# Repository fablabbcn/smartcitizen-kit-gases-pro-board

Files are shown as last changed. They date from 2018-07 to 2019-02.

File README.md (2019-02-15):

# Smart Citizen Kit 2.0 Gases Pro Board 

[]()


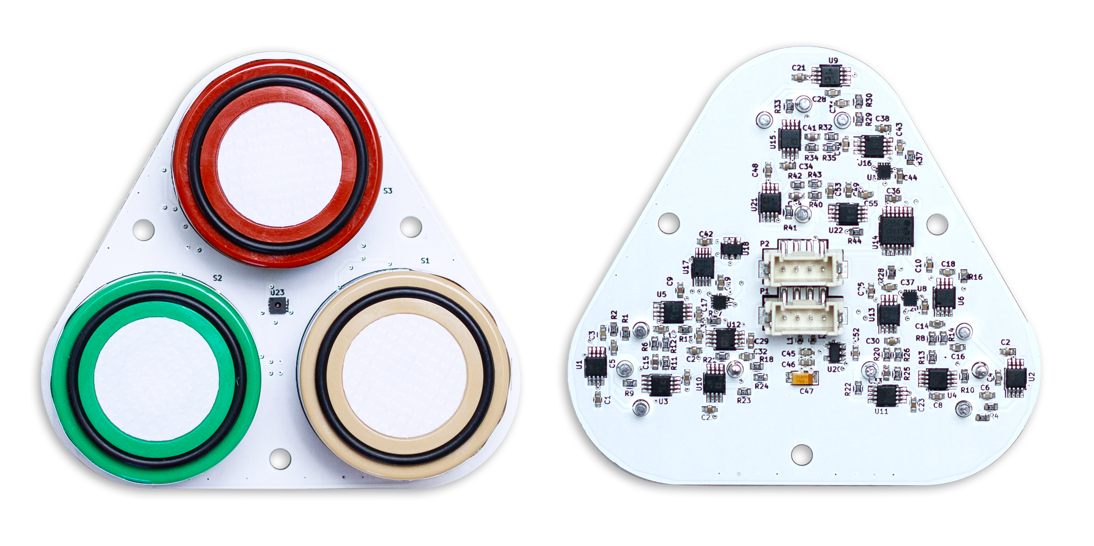
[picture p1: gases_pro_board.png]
Gases Pro Board


### The core firmware (C++)

The technology used:

* Arduino Zero Core
* Platformio

#### Uploading the firmware to the board

After clonning the repository:

1. In folder ./firmware run:

  * `pio run`

2. This step will **take a while**. Once it finished plug the board over USB and run:

  * `pio run -t upload`

## Documentation

Full documentation under development. Follow the [forum](https://forum.smartcitizen.me/) and [twitter](https://twitter.com/SmartCitizenKit) for updates.

## Related Smart Citizen repositories

* Smart Citizen Kit 2.0 [github.com/fablabbcn/smartcitizen-kit-20](https://github.com/fablabbcn/smartcitizen-kit-20)
* Platform Core API [github.com/fablabbcn/smartcitizen-api](https://github.com/fablabbcn/smartcitizen-api)
* Platform Web [github.com/fablabbcn/smartcitizen-web](https://github.com/fablabbcn/smartcitizen-web)
* Platform Onboarding [github.com/fablabbcn/smartcitizen-onboarding-app](https://github.com/fablabbcn/smartcitizen-onboarding-app)
* Kit Enclosures [github.com/fablabbcn/smartcitizen-enclosures](https://github.com/fablabbcn/smartcitizen-enclosures)
* Useful software resources for communities [github.com/fablabbcn/smartcitizen-toolkit](https://github.com/fablabbcn/smartcitizen-toolkit)

## License

All the software unless stated is released under [GNU GPL v3.0](https://github.com/fablabbcn/smartcitizen-kit-20/blob/master/LICENSE) and the hardware design files under [CERN OHL v1.2](https://github.com/fablabbcn/smartcitizen-kit-20/blob/master/hardware/LICENSE)

## Credits

Smart Citizen Team 2012-18

## Funding

This work has received funding from the European Union's Horizon 2020 research and innovation program under the grant agreement [No. 689954](https://cordis.europa.eu/project/rcn/202639_en.html)

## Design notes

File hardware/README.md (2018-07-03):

Smart Citizen Kit 2.0 PM Board Hardware
=======================================

This folder contains the KiCad design files for the Smart Citizen Kit 2.0 PM Board

## Folders

* **SCK_2.0_GASES_PRO_BOARD_rev3** The SCK Gases Pro Alphasense Driver Board
* **SCK_2.0_GASES_PRO_BOARD_TEST_UTIL_rev2** The SCK Gases Pro Calibration and Test Util

## License

All the software is released under [GNU GPL v3.0](https://github.com/fablabbcn/smartcitizen-kit-20/blob/master/LICENSE) and the hardware design files under [CERN OHL v1.2](https://github.com/fablabbcn/smartcitizen-kit-20/blob/master/hardware/LICENSE)

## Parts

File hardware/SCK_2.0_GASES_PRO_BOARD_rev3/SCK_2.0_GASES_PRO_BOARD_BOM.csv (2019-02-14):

Id | Designator | Package | Quantity | Designation | Manufacturer | Manufacturer Part Number | Description | Mouser Part Number | Mouser Alternative Part Number | Mouser Stock | Digikey Part Number | Digikey Stock | Seeedstudio Part Number | Seeedstudio Stock
1 | U7,U8,U19 | QFN14(2X2MM) | 3 | TPL-0102 | Texas Instruments | TPL0102-100RUCR | Digital Potentiometer ICs Digital Potentiometer ICs 256 Taps Dual Ch Digital Pot | 595-TPL0102-100RUCR |  |  | 296-28379-1-ND
4 | U2,U1,U3,U4,U9,U10,U11,U15,U21 | MSOP-8_3x3mm_Pitch0.65mm | 9 | ADA4528-1 | Analog Devices Inc. | ADA4528-1ARMZ | Precision Amplifiers Precision Amplifiers 5V Ultralow Noise Zero-Drift RRIO Dual | 584-ADA4528-1ARMZ |  |  | ADA4528-1ARMZ-R7CT-ND
6 | U6,U5,U12,U13,U16,U22 | MSOP-8_3x3mm_Pitch0.65mm | 6 | ADA4528-2 | Analog Devices Inc. | ADA4528-2ARMZ | Precision Amplifiers Precision Amplifiers 18V LowPower RRIO Untrimmed CmosAmp | 584-ADA4528-2ARMZ |  |  | ADA4528-2ARMZ-R7CT-ND
21 | U14 | TSSOP-14_4.4x5mm_Pitch0.65mm | 1 | MCP3424 | Microchip | MCP3424-E/ST | Analog to Digital Converters - ADC Analog to Digital Converters - ADC 18B delta-sigma ADC dual Ch 4sps | 579-MCP3424-E/ST |  |  | MCP3424-E/ST-ND
22 | U18 | SOT-23-6 | 1 | 24AA025UID | Microchip | 24AA025UIDT-I/OT | EEPROM EEPROM 2K I2C EE Unique ID | 579-24AA025UIDT-I/OT |  |  | 24AA025UIDT-I/OTCT-ND
23 | U20 | SOT-23-5 | 1 | REF-1930 | Texas Instruments | REF1930AIDDCT | Voltage References Voltage References Dual Output Vref & Vref/2 Voltage Ref | 595-REF1930AIDDCT |  |  | 296-38443-1-ND
24 | U23 | DFN-6-1EP_3x3mm_Pitch0.95mm | 1 | SHT31 | Sensirion | SHT31-DIS-B | Board Mount Humidity Sensors Board Mount Humidity Sensors +/- 2%RH 8-PIN DFN pkg | 403-SHT31-DIS-F |  |  | 1649-1066-1-ND
25 | U17 | MSOP-10_3x3mm_Pitch0.5mm | 1 | MCP3423 | Microchip | MCP3423-E/UN | Analog to Digital Converters - ADC 18B delta-sigma ADC dual Ch 4sps | 579-MCP3423-E/UN |  |  | MCP3423-E/UN-ND
3 | S3,S2,S1 | Alphasense_B-4 | 12 | Alphasense_B_Conector | Harwin | H3183-01 | Circuit Board Hardware - PCB Circuit Board Hardware - PCB 1mm PC BOARD SOCKET TIN | 855-H3183-01 |  |  | 952-1468-ND
8 | P2,P1 | HW4-SMD-2.0 | 2 | CONN_01X04 | Seedstudio | CONN_01X04 | 1125S-SMT-4P |  |  |  |  |  | 320110030
15 | L1,L2 | R_0402 | 2 | MPZ1005S121C | TDK | MPZ1005S121C | Ferrite Beads Ferrite Beads 120ohms, 1.2A 0.09ohms | 810-MPZ1005S121C
5 | C20,C1,C2,C7,C8,C9,C10,C19,C21,C22,C23,C24,C25,C34,C36,C38,C42,C44,C46,C48,C49,C52 | C_0603 | 22 | 100n | AVX | 06033C104K4T2A | Multilayer Ceramic Capacitors MLCC - SMD/SMT 25V .1uF X7R 0603 10% Tol | 581-06033C104K4
9 | C3,C4,C5,C6,C28,C31 | C_0603 | 6 | 20n | AVX | 0603ZC223JAT2A | Multilayer Ceramic Capacitors MLCC - SMD/SMT Multilayer Ceramic Capacitors MLCC - SMD/SMT 10V .022uF X7R 0603 5% Tol | 581-0603ZC223JAT2A | 710-885012206042 |  | 0603ZC223JAT2A-ND
10 | C11,C12,C26,C27,C39,C50 | C_0603 | 6 | 220n | AVX | 0603ZC224JAT2A | Multilayer Ceramic Capacitors MLCC - SMD/SMT Multilayer Ceramic Capacitors MLCC - SMD/SMT 10V .22uF X7R 0603 5% Tol | 581-0603ZC224J |  |  | 478-6035-1-ND
11 | C13,C14,C29,C30,C40,C53 | C_0603 | 6 | 2.2µ | AVX | 0603ZC225KAT2A | Multilayer Ceramic Capacitors MLCC - SMD/SMT Multilayer Ceramic Capacitors MLCC - SMD/SMT 10V 2.2uF X7R 0603 10% Tol | 581-0603ZC225KAT2A
12 | C15,C16,C32,C33,C41,C54 | C_0603 | 6 | 6.8µ | TDK | C1608X5R1A685K080AC | Multilayer Ceramic Capacitors MLCC - SMD/SMT Multilayer Ceramic Capacitors MLCC - SMD/SMT 0805 6.8uF 10volts X7R 10% | 810-C2012X7R1A685K1C |  |  | 445-14529-1-ND
13 | C17,C18,C35,C37,C43,C45,C55 | C_0603 | 7 | 10n | AVX | 0603ZC103JAT2A | Multilayer Ceramic Capacitors MLCC - SMD/SMT Multilayer Ceramic Capacitors MLCC - SMD/SMT 10V .01uF X7R 0603 5% Tol | 581-0603ZC103J |  |  | 0603ZC103JAT2A-ND
14 | C47 | CP_Tantalum_Case-A_EIA-3216-18_Reflow | 1 | 10µ Tan. | AVX | TRJA106K010R1800 | Tantalum Capacitors - Solid SMD Tantalum Capacitors - Solid SMD 10uF +/-10% 10V ESR=1800 | 581-TRJA106K010R1800
16 | R1,R2,R3,R4,R15,R16,R27,R28,R29,R30,R37,R44 | R_0603 | 12 | 10kΩ | Vishay | MCT06030C1002FP500 | Thin Film Resistors - SMD Thin Film Resistors - SMD .1W 10Kohms 1% 0603 50ppm Auto | 594-MCT06030C1002FP5 |  |  | MCT0603-10.0K-CFCT-ND
17 | R5,R7,R17,R19,R31,R39 | R_0603 | 6 | 150kΩ | Vishay | MCT06030C1503FP500 | Thin Film Resistors - SMD Thin Film Resistors - SMD .1W 150Kohm 1% 0603 50ppm Auto | 594-MCT06030C1503FP5 |  |  | MCT0603-150K-CFCT-ND
18 | R6,R8,R11,R13,R18,R20,R23,R25,R32,R34,R40,R42 | R_0603 | 12 | 5.6kΩ | Vishay | MCT06030C5601FP500 | Thin Film Resistors - SMD Thin Film Resistors - SMD .1W 5.6Kohm 1% 0603 50ppm Auto | 594-MCT06030C5601FP5 |  |  | MCT0603-5.60K-CFCT-ND
19 | R9,R10,R21,R22,R33,R41 | R_0603 | 6 | 100Ω | Vishay | MCT06030C1000FP500 | Thin Film Resistors - SMD Thin Film Resistors - SMD .1W 100ohm 1% 0603 50ppm Auto | 594-MCT06030C1000FP5 |  |  | MCT0603-100-CFCT-ND
20 | R12,R14,R24,R26,R35,R43 | R_0603 | 6 | 12kΩ | Vishay | MCT06030C1202FP500 | Thin Film Resistors - SMD Thin Film Resistors - SMD .1W 12Kohm 1% 0603 50ppm Auto | 594-MCT06030C1202FP5 |  |  | MCT0603-12.0K-CFCT-ND
 | *All resistor Thin metal film
 | All capacitor MMLC X7R (except tantalum)

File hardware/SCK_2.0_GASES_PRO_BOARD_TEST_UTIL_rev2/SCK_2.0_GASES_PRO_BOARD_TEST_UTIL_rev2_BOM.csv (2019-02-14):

Id | Designator | Package | Quantity | Designation | Manufacturer Part Number | Description | Mouser Part Number | Mouser Alternative Part Number | Mouser Stock | Digikey Part Number | Digikey Stock | Seeedstudio Part Number | Seeedstudio Stock
2 | U3,U1 | TSSOP-14_4.4x5mm_Pitch0.65mm | 2 | MCP6V34-E/ST
3 | U4,U2 | TSSOP-14_4.4x5mm_Pitch0.65mm | 2 | MCP4651-103/ST |  | Digital pot. 10K | 579-MCP4651-103/ST
4 | A | 1pin | 1 | curr_out_2 | Keystone |  | 534-1402-3
5 | W | 1pin | 1 | curr_out_1 | Keystone |  | 534-1402-3
6 | Power/Comm | HW4-SMD-2.0 | 1 | CONN_01X04 |  | 1125S-SMT-4P |  |  |  |  |  | 320110030
7 | U5 | SOT-23-5 | 1 | REF-1930 | Texas Instruments | REF1930AIDDCT | Voltage References Voltage References Dual Output Vref & Vref/2 Voltage Ref | 595-REF1930AIDDCT |  | Yes | 296-38443-1-ND | Yes
8 | C1,C3,C6,C7,C10,C11,C12,C13 | C_0603_HandSoldering | 8 | 100n
9 | C2,C8 | C_0603_HandSoldering | 2 | 10n
10 | C4 | C_0603_HandSoldering | 1 | 1u
11 | C5,C9 | C_0603_HandSoldering | 2 | 22p
12 | R2,R12 | R_0805_HandSoldering | 2 | 1M 0.5%
13 | R4,R6,R8,R9,R10,R14,R16,R18,R19,R20,R21,R25 | R_0603_HandSoldering | 12 | 100k 0.5% o 0.1%
14 | R5,R15 | R_0603_HandSoldering | 2 | 100
15 | R7,R17 | R_0603_HandSoldering | 2 | 1k
16 | R22,R26 | R_0603_HandSoldering | 2 | 4.3M
 | All resistors metal film
 | All capacitors X7R or C0G

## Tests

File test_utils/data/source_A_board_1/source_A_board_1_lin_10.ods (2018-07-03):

Corriente pedida |  | corriente leida_A | diff
-1400 | - | -1400.23 | 0.23 | pot0A_g | 3 | - | pot1A_f | 196
-1399 | - | -1399.19 | 0.19 | pot0A_g | 3 | - | pot1A_f | 207
-1398 | - | -1398.25 | 0.25 | pot0A_g | 3 | - | pot1A_f | 217
-1397 | - | -1397.17 | 0.17 | pot0A_g | 3 | - | pot1A_f | 228
-1396 | - | -1396.23 | 0.23 | pot0A_g | 3 | - | pot1A_f | 238
-1395 | - | -1395.19 | 0.19 | pot0A_g | 3 | - | pot1A_f | 249
-1394 | - | -1394.14 | 0.14 | pot0A_g | 4 | - | pot1A_f | 90
-1393 | - | -1393.2 | 0.2 | pot0A_g | 4 | - | pot1A_f | 100
-1392 | - | -1392.17 | 0.17 | pot0A_g | 4 | - | pot1A_f | 111
-1391 | - | -1391.2 | 0.2 | pot0A_g | 4 | - | pot1A_f | 121
-1390 | - | -1390.13 | 0.13 | pot0A_g | 4 | - | pot1A_f | 132
-1389 | - | -1389.17 | 0.17 | pot0A_g | 4 | - | pot1A_f | 142
-1388 | - | -1388.13 | 0.13 | pot0A_g | 4 | - | pot1A_f | 153
-1387 | - | -1387.14 | 0.14 | pot0A_g | 4 | - | pot1A_f | 163
-1386 | - | -1386.11 | 0.11 | pot0A_g | 4 | - | pot1A_f | 174
-1385 | - | -1385.17 | 0.17 | pot0A_g | 4 | - | pot1A_f | 184
-1384 | - | -1384.09 | 0.09 | pot0A_g | 4 | - | pot1A_f | 195
-1383 | - | -1383.16 | 0.16 | pot0A_g | 4 | - | pot1A_f | 205
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

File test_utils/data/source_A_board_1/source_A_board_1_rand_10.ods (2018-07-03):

item | Corriente pedida |  | delay |  | corriente leida_A | diff
0 | -1102 | -> | 2000 | - | -1101.45 | -0.55
1 | 668 | -> | 2270 | - | 667.7 | 0.3
2 | -341 | -> | 1509 | - | -340.67 | -0.33
3 | 467 | -> | 1308 | - | 466.73 | 0.27
4 | 395 | -> | 572 | - | 394.97 | 0.03
5 | -492 | -> | 1387 | - | -491.64 | -0.36
6 | 813 | -> | 1805 | - | 812.59 | 0.41
7 | -893 | -> | 2206 | - | -892.69 | -0.31
8 | -374 | -> | 1019 | - | -374.25 | 0.25
9 | -48 | -> | 826 | - | -48.45 | 0.45
10 | 37 | -> | 585 | - | 36.64 | 0.36
11 | 556 | -> | 1019 | - | 555.48 | 0.52
12 | -1053 | -> | 2109 | - | -1052.72 | -0.28
13 | -1146 | -> | 593 | - | -1145.55 | -0.45
14 | 837 | -> | 2483 | - | 836.59 | 0.41
15 | 1191 | -> | 854 | - | 1190.25 | 0.75
16 | 30 | -> | 1661 | - | 30.16 | -0.16
17 | 1084 | -> | 1554 | - | 1083.53 | 0.47
18 | -1126 | -> | 2710 | - | -1125.69 | -0.31
19 | 122 | -> | 1748 | - | 121.67 | 0.33
20 | -1271 | -> | 1893 | - | -1270.7 | -0.3
21 | 310 | -> | 2081 | - | 309.61 | 0.39
22 | -953 | -> | 1763 | - | -952.81 | -0.19
23 | 1194 | -> | 2647 | - | 1193.56 | 0.44
24 | -912 | -> | 2606 | - | -911.87 | -0.13
25 | -1353 | -> | 941 | - | -1352.44 | -0.56
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

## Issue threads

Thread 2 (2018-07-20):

No need to wait after Wire.requestFrom().

Koepel, 2018-07-20:
The timeout after Wire.requestFrom() with millis() in the file "GasesBoardTester.cpp" is not needed.
Explanation: [Common-mistakes#1](https://github.com/Koepel/How-to-use-the-Arduino-Wire-library/wiki/Common-mistakes#1)

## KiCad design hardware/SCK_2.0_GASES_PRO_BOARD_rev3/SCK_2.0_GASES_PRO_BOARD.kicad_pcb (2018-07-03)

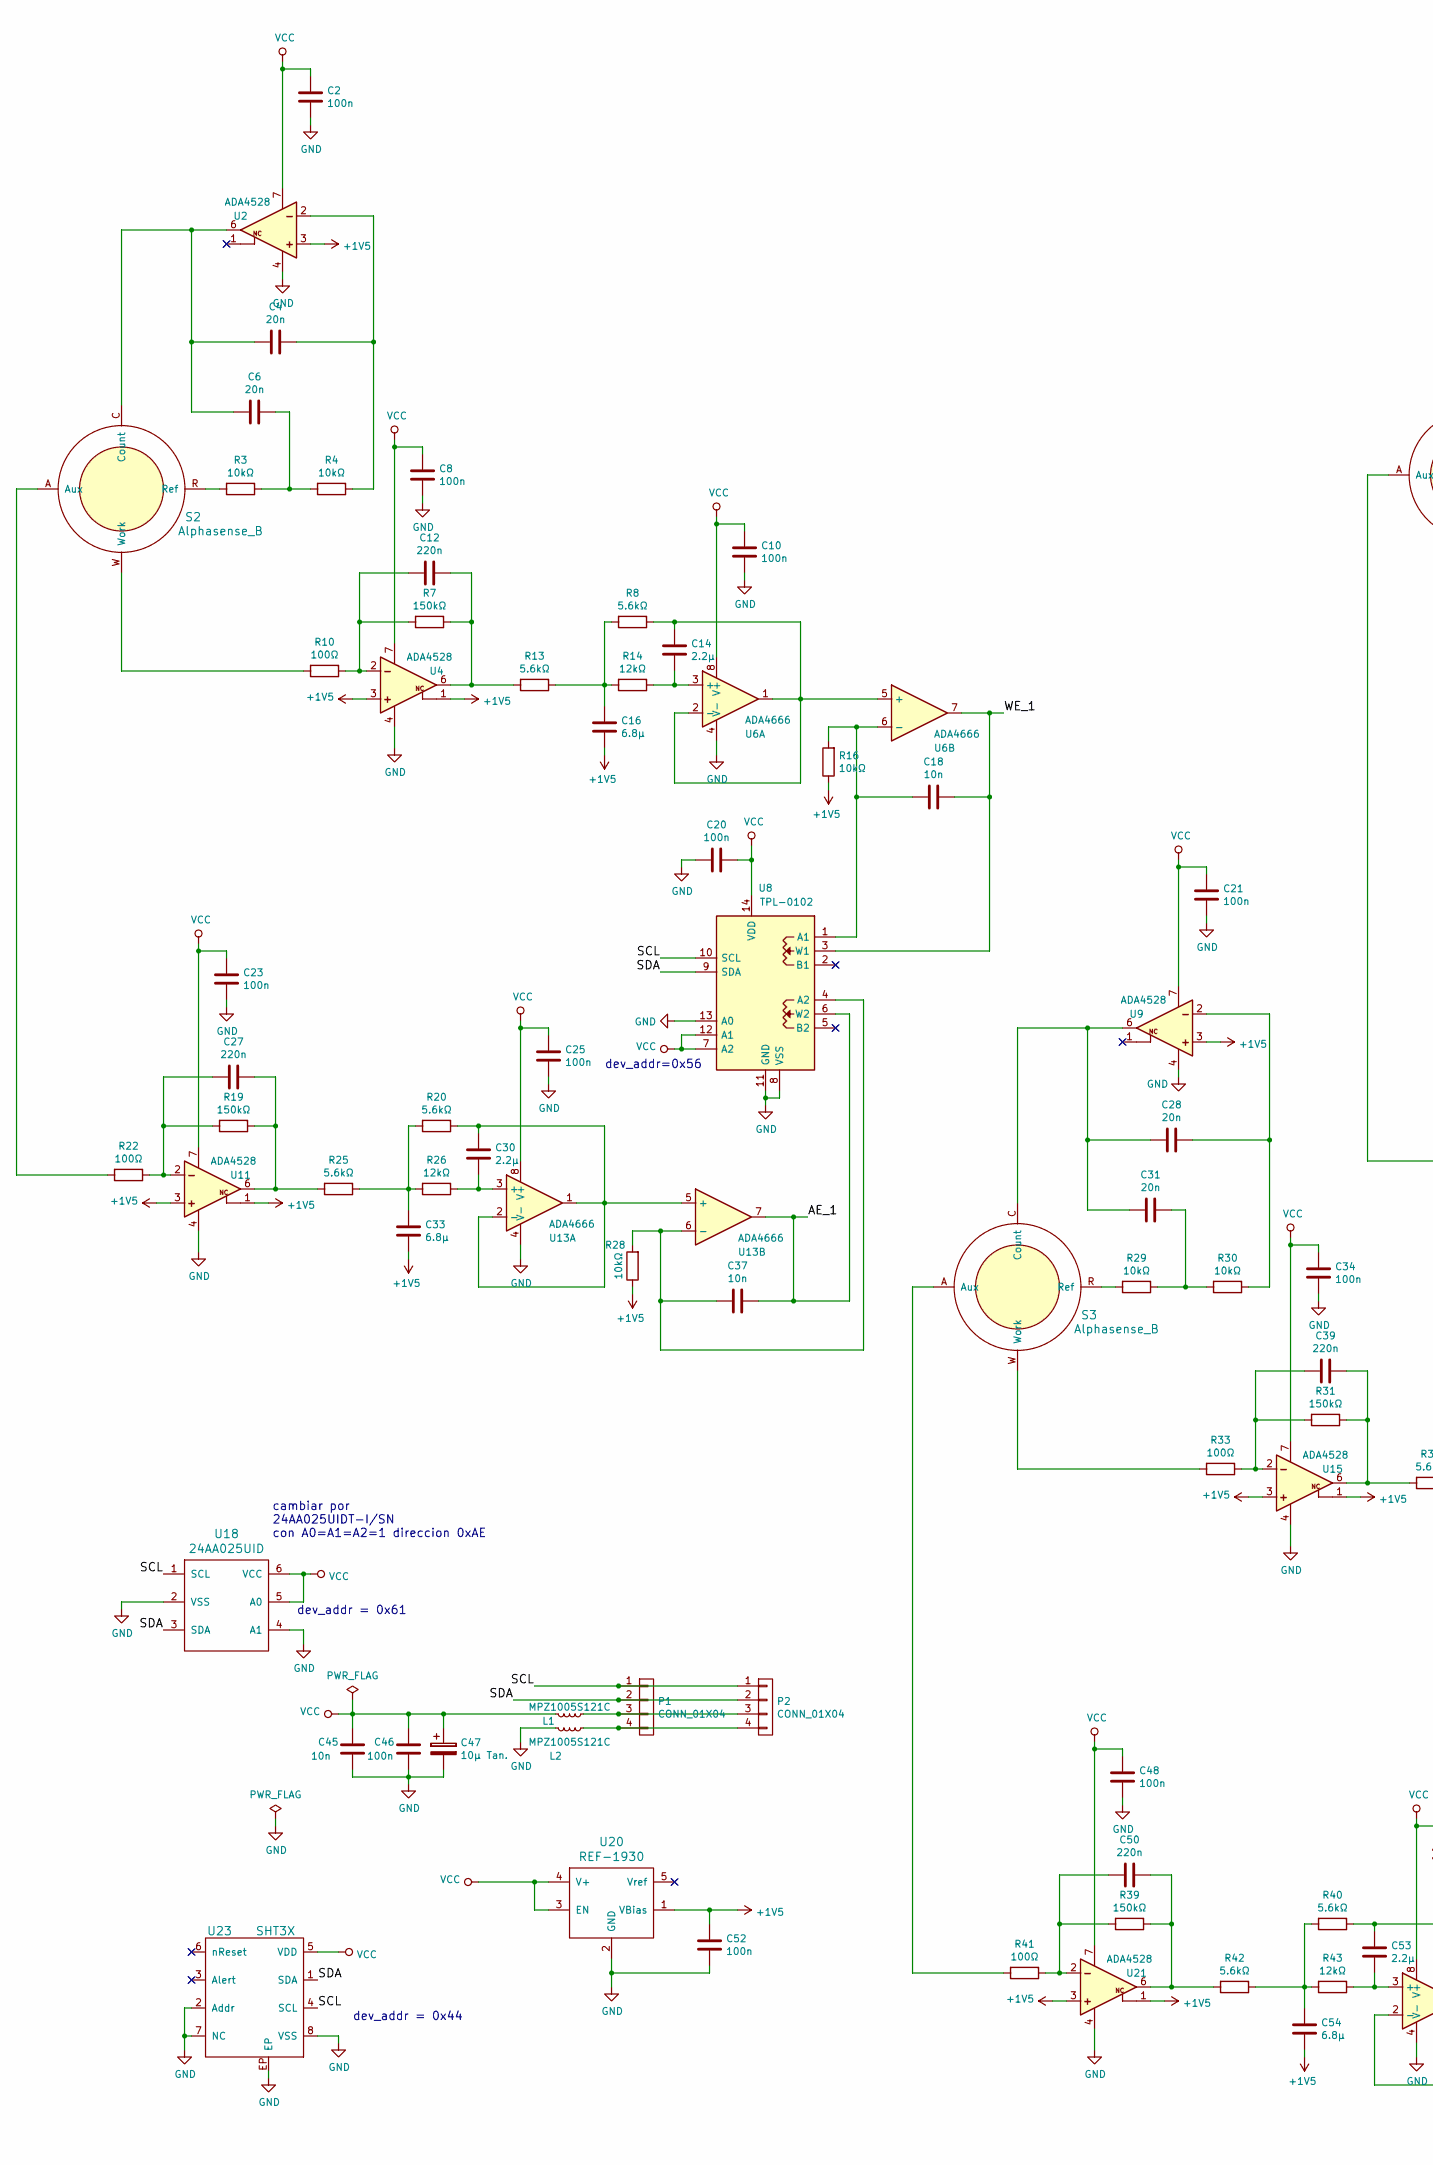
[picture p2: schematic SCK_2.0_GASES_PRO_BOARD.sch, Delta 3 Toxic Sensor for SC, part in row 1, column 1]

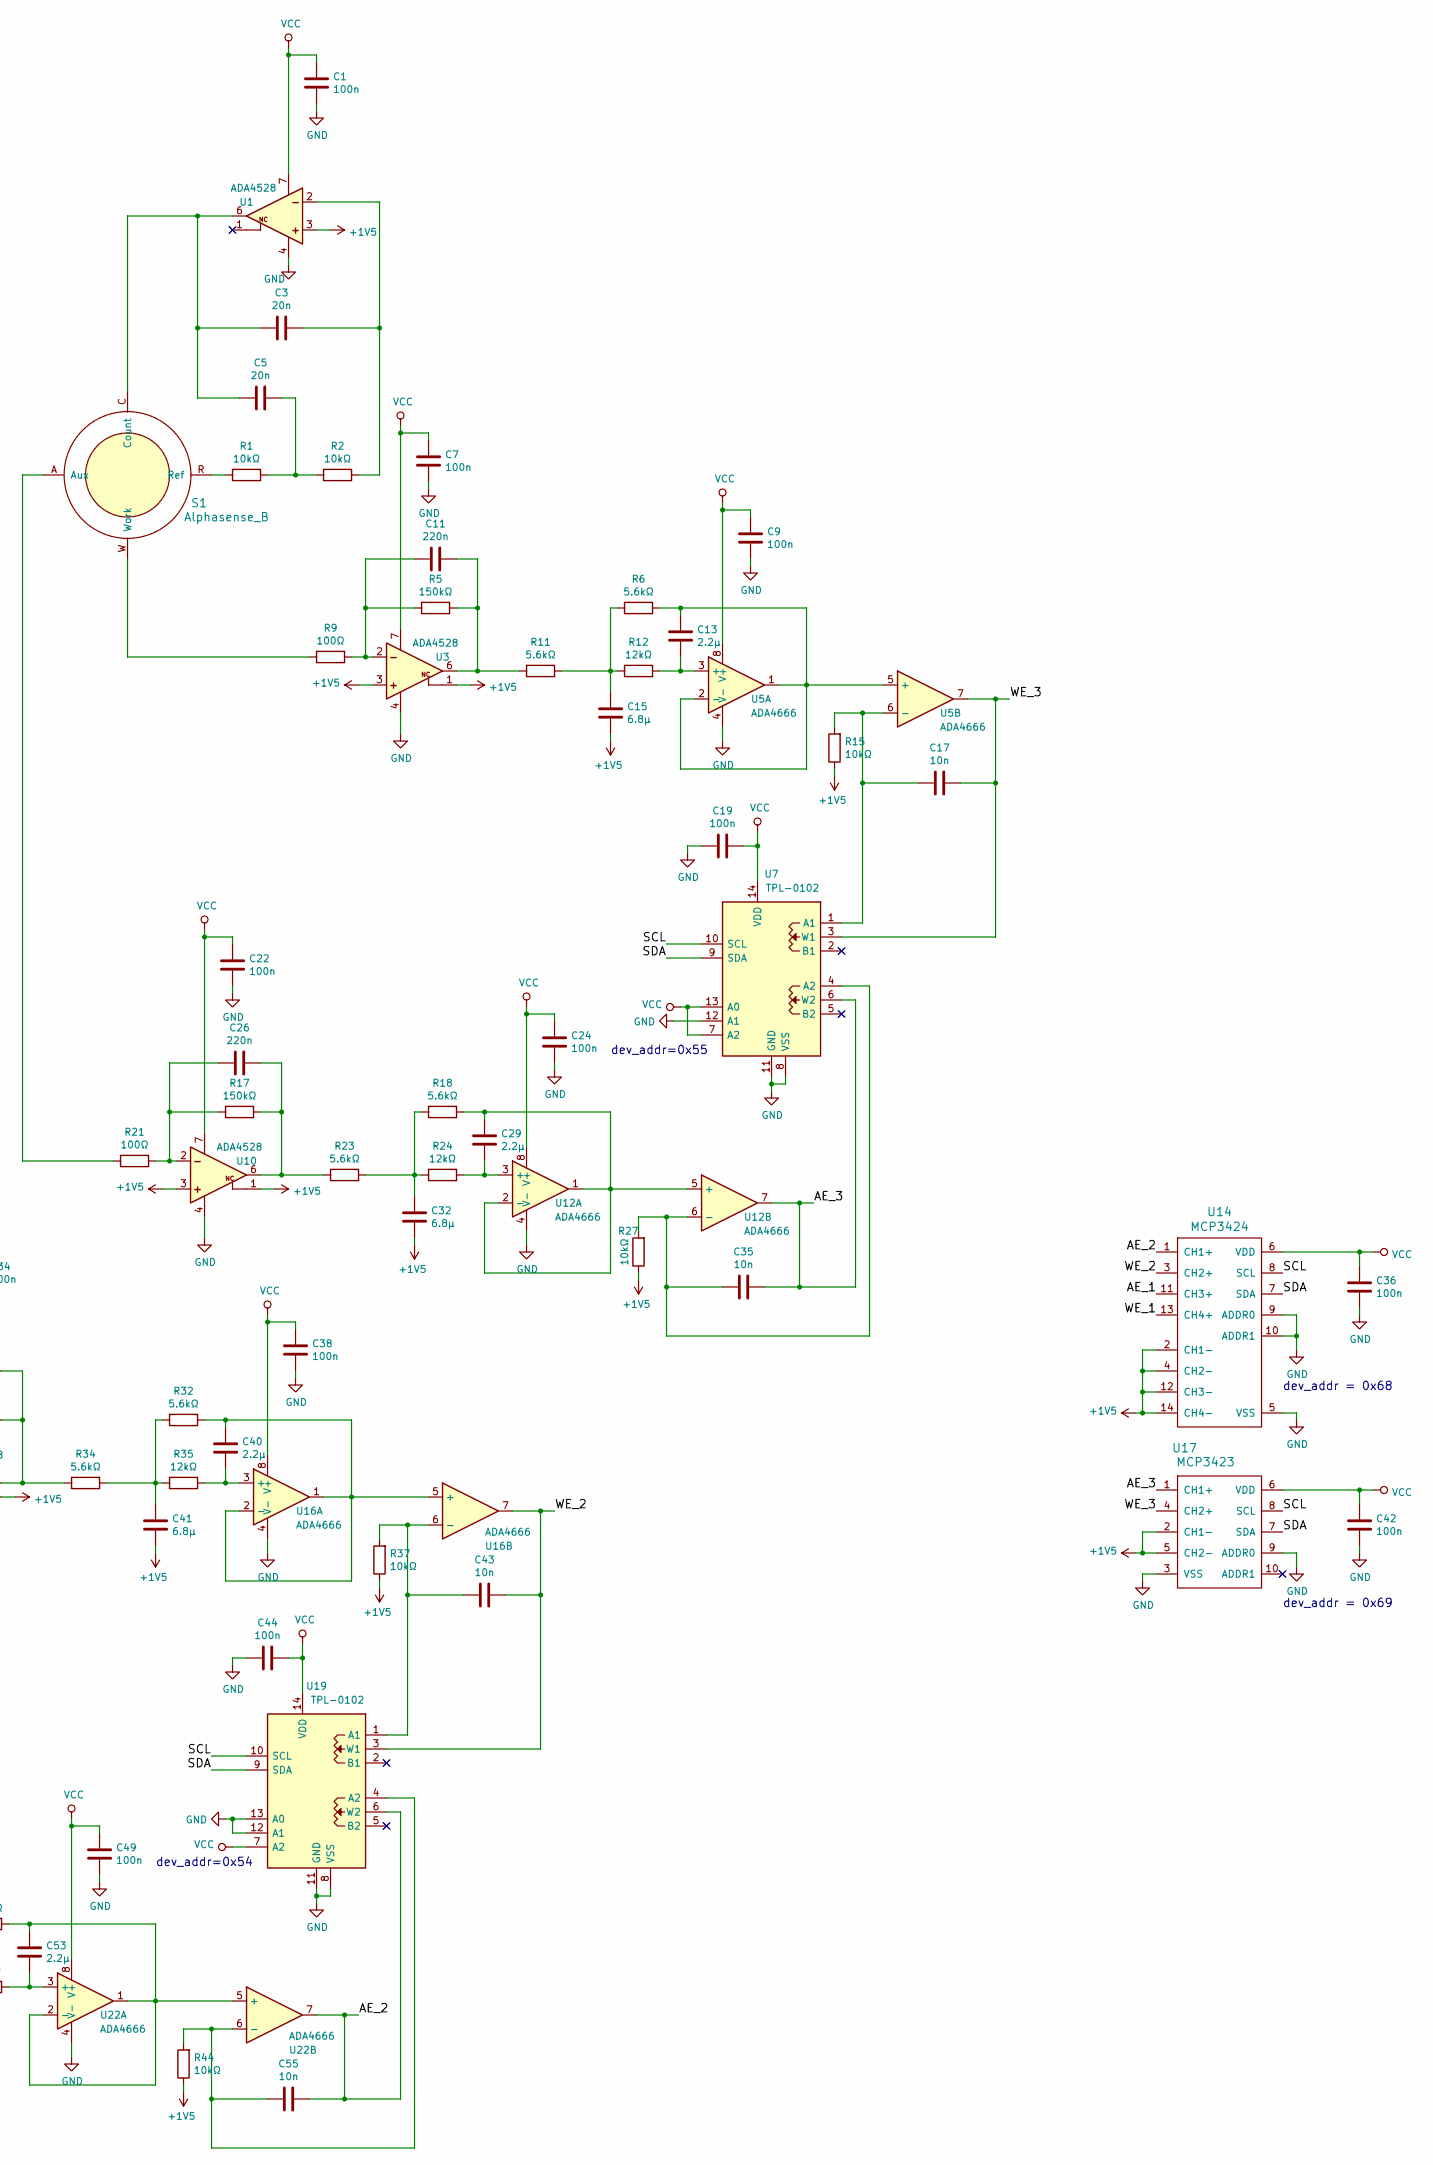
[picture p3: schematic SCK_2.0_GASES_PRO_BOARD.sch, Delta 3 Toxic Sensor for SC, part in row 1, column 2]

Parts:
C1, C2, C7, C8, C9, C10, C19, C20, C21, C22, C23, C24, C25, C34, C36, C38, C42, C44, C46, C48, C49, C52: 100n; C_0603
C3, C4, C5, C6, C28, C31: 20n; C_0603
C11, C12, C26, C27, C39, C50: 220n; C_0603
C13, C14, C29, C30, C40, C53: 2.2µ; C_0603
C15, C16, C32, C33, C41, C54: 6.8µ; C_0603
C17, C18, C35, C37, C43, C45, C55: 10n; C_0603
C47: 10µ Tan.; CP_Tantalum_Case-A_EIA-3216-18_Reflow
L1, L2: MPZ1005S121C; R_0402
P1, P2: CONN_01X04; HW4-SMD-2.0
R1, R2, R3, R4, R15, R16, R27, R28, R29, R30, R37, R44: 10kΩ; R_0603
R5, R7, R17, R19, R31, R39: 150kΩ; R_0603
R6, R8, R11, R13, R18, R20, R23, R25, R32, R34, R40, R42: 5.6kΩ; R_0603
R9, R10, R21, R22, R33, R41: 100Ω; R_0603
R12, R14, R24, R26, R35, R43: 12kΩ; R_0603
S1, S2, S3: Alphasense_B; Alphasense_B-4
U1, U2, U3, U4, U9, U10, U11, U15, U21: ADA4528; MSOP-8_3x3mm_Pitch0.65mm
U5, U6, U12, U13, U16, U22: ADA4666; MSOP-8_3x3mm_Pitch0.65mm
U7, U8, U19: TPL-0102; QFN14(2X2MM)
U14: MCP3424; TSSOP-14_4.4x5mm_Pitch0.65mm
U17: MCP3423; MSOP-10_3x3mm_Pitch0.5mm
U18: 24AA025UID; SOT-23-6
U20: REF-1930; SOT-23-5
U23: SHT3X; DFN-8-1EP_2x2mm_Pitch0.5mm

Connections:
+1V5: C15.1, C16.1, C32.1, C33.1, C41.1, C52.1, C54.1, R15.1, R16.1, R27.1, R28.1, R37.1, R44.1, U1.3 (NOT-INV.INPUT), U2.3 (NOT-INV.INPUT), U3.1 (NC), U3.3 (NOT-INV.INPUT), U4.1 (NC), U4.3 (NOT-INV.INPUT), U9.3 (NOT-INV.INPUT), U10.1 (NC), U10.3 (NOT-INV.INPUT), U11.1 (NC), U11.3 (NOT-INV.INPUT), U14.2 (CH1-), U14.4 (CH2-), U14.12 (CH3-), U14.14 (CH4-), U15.1 (NC), U15.3 (NOT-INV.INPUT), U17.2 (CH1-), U17.5 (CH2-), U20.1 (VBias), U21.1 (NC), U21.3 (NOT-INV.INPUT)
/AE_1: C37.2, U8.6 (W2), U13.7, U14.11 (CH3+)
/AE_2: C55.2, U14.1 (CH1+), U19.6 (W2), U22.7
/AE_3: C35.2, U7.6 (W2), U12.7, U17.1 (CH1+)
/SCL: P1.1, P2.1, U7.10 (SCL), U8.10 (SCL), U14.8 (SCL), U17.8 (SCL), U18.1 (SCL), U19.10 (SCL), U23.4 (SCL)
/SDA: P1.2, P2.2, U7.9 (SDA), U8.9 (SDA), U14.7 (SDA), U17.7 (SDA), U18.3 (SDA), U19.9 (SDA), U23.1 (SDA)
/WE_1: C18.2, U6.7, U8.3 (W1), U14.13 (CH4+)
/WE_2: C43.2, U14.3 (CH2+), U16.7, U19.3 (W1)
/WE_3: C17.2, U5.7, U7.3 (W1), U17.4 (CH2+)
GND: C1.2, C2.2, C7.2, C8.2, C9.2, C10.2, C19.1, C20.1, C21.2, C22.2, C23.2, C24.2, C25.2, C34.2, C36.2, C38.2, C42.2, C44.1, C45.2, C46.2, C47.2, C48.2, C49.2, C52.2, L2.2, U1.4 (V-), U2.4 (V-), U3.4 (V-), U4.4 (V-), U5.4 (V-), U6.4 (V-), U7.8 (VSS), U7.11 (GND), U7.12 (A1), U8.8 (VSS), U8.11 (GND), U8.13 (A0), U9.4 (V-), U10.4 (V-), U11.4 (V-), U12.4 (V-), U13.4 (V-), U14.5 (VSS), U14.9 (ADDR0), U14.10 (ADDR1), U15.4 (V-), U16.4 (V-), U17.3 (VSS), U17.9 (ADDR0), U18.2 (VSS), U18.4 (A1), U19.8 (VSS), U19.11 (GND), U19.12 (A1), U19.13 (A0), U20.2 (GND), U21.4 (V-), U22.4 (V-), U23.2 (Addr), U23.7 (NC), U23.8 (VSS), U23.9, U23.EP
unnamed: C3.1, R2.1, U1.2 (INV.INPUT)
unnamed: C3.2, C5.2, S1.C (Count), U1.6 (OUTPUT)
unnamed: C4.1, R4.1, U2.2 (INV.INPUT)
unnamed: C4.2, C6.2, S2.C (Count), U2.6 (OUTPUT)
unnamed: C5.1, R1.1, R2.2
unnamed: C6.1, R3.1, R4.2
unnamed: C11.1, R5.1, R11.2, U3.6 (OUTPUT)
unnamed: C11.2, R5.2, R9.1, U3.2 (INV.INPUT)
unnamed: C12.1, R7.1, R13.2, U4.6 (OUTPUT)
unnamed: C12.2, R7.2, R10.1, U4.2 (INV.INPUT)
unnamed: C13.1, R12.1, U5.3 (+)
unnamed: C13.2, R6.1, U5.1, U5.2 (-), U5.5 (+)
unnamed: C14.1, R14.1, U6.3 (+)
unnamed: C14.2, R8.1, U6.1, U6.2 (-), U6.5 (+)
unnamed: C15.2, R6.2, R11.1, R12.2
unnamed: C16.2, R8.2, R13.1, R14.2
unnamed: C17.1, R15.2, U5.6 (-), U7.1 (A1)
unnamed: C18.1, R16.2, U6.6 (-), U8.1 (A1)
unnamed: C26.1, R17.1, R23.2, U10.6 (OUTPUT)
unnamed: C26.2, R17.2, R21.1, U10.2 (INV.INPUT)
unnamed: C27.1, R19.1, R25.2, U11.6 (OUTPUT)
unnamed: C27.2, R19.2, R22.1, U11.2 (INV.INPUT)
unnamed: C28.1, R30.1, U9.2 (INV.INPUT)
unnamed: C28.2, C31.2, S3.C (Count), U9.6 (OUTPUT)
unnamed: C29.1, R24.1, U12.3 (+)
unnamed: C29.2, R18.1, U12.1, U12.2 (-), U12.5 (+)
unnamed: C30.1, R26.1, U13.3 (+)
unnamed: C30.2, R20.1, U13.1, U13.2 (-), U13.5 (+)
unnamed: C31.1, R29.1, R30.2
unnamed: C32.2, R18.2, R23.1, R24.2
unnamed: C33.2, R20.2, R25.1, R26.2
unnamed: C35.1, R27.2, U7.4 (A2), U12.6 (-)
unnamed: C37.1, R28.2, U8.4 (A2), U13.6 (-)
unnamed: C39.1, R31.1, R34.2, U15.6 (OUTPUT)
unnamed: C39.2, R31.2, R33.1, U15.2 (INV.INPUT)
unnamed: C40.1, R35.1, U16.3 (+)
unnamed: C40.2, R32.1, U16.1, U16.2 (-), U16.5 (+)
unnamed: C41.2, R32.2, R34.1, R35.2
unnamed: C43.1, R37.2, U16.6 (-), U19.1 (A1)
unnamed: C50.1, R39.1, R42.2, U21.6 (OUTPUT)
unnamed: C50.2, R39.2, R41.1, U21.2 (INV.INPUT)
unnamed: C53.1, R43.1, U22.3 (+)
unnamed: C53.2, R40.1, U22.1, U22.2 (-), U22.5 (+)
unnamed: C54.2, R40.2, R42.1, R43.2
unnamed: C55.1, R44.2, U19.4 (A2), U22.6 (-)
unnamed: L1.1, P1.3, P2.3
unnamed: L2.1, P1.4, P2.4
unnamed: R1.2, S1.R (Ref)
unnamed: R3.2, S2.R (Ref)
unnamed: R9.2, S1.W (Work)
unnamed: R10.2, S2.W (Work)
unnamed: R21.2, S1.A (Aux)
unnamed: R22.2, S2.A (Aux)
unnamed: R29.2, S3.R (Ref)
unnamed: R33.2, S3.W (Work)
unnamed: R41.2, S3.A (Aux)
VCC: C1.1, C2.1, C7.1, C8.1, C9.1, C10.1, C19.2, C20.2, C21.1, C22.1, C23.1, C24.1, C25.1, C34.1, C36.1, C38.1, C42.1, C44.2, C45.1, C46.1, C47.1, C48.1, C49.1, L1.2, U1.7 (V+), U2.7 (V+), U3.7 (V+), U4.7 (V+), U5.8 (V+), U6.8 (V+), U7.7 (A2), U7.13 (A0), U7.14 (VDD), U8.7 (A2), U8.12 (A1), U8.14 (VDD), U9.7 (V+), U10.7 (V+), U11.7 (V+), U12.8 (V+), U13.8 (V+), U14.6 (VDD), U15.7 (V+), U16.8 (V+), U17.6 (VDD), U18.5 (A0), U18.6 (VCC), U19.7 (A2), U19.14 (VDD), U20.3 (EN), U20.4 (V+), U21.7 (V+), U22.8 (V+), U23.5 (VDD)

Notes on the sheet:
dev_addr=0x56
dev_addr=0x54
dev_addr=0x55
dev_addr = 0x61
dev_addr = 0x69
dev_addr = 0x68
dev_addr = 0x44
cambiar por 24AA025UIDT-I/SN con A0=A1=A2=1 direccion 0xAE

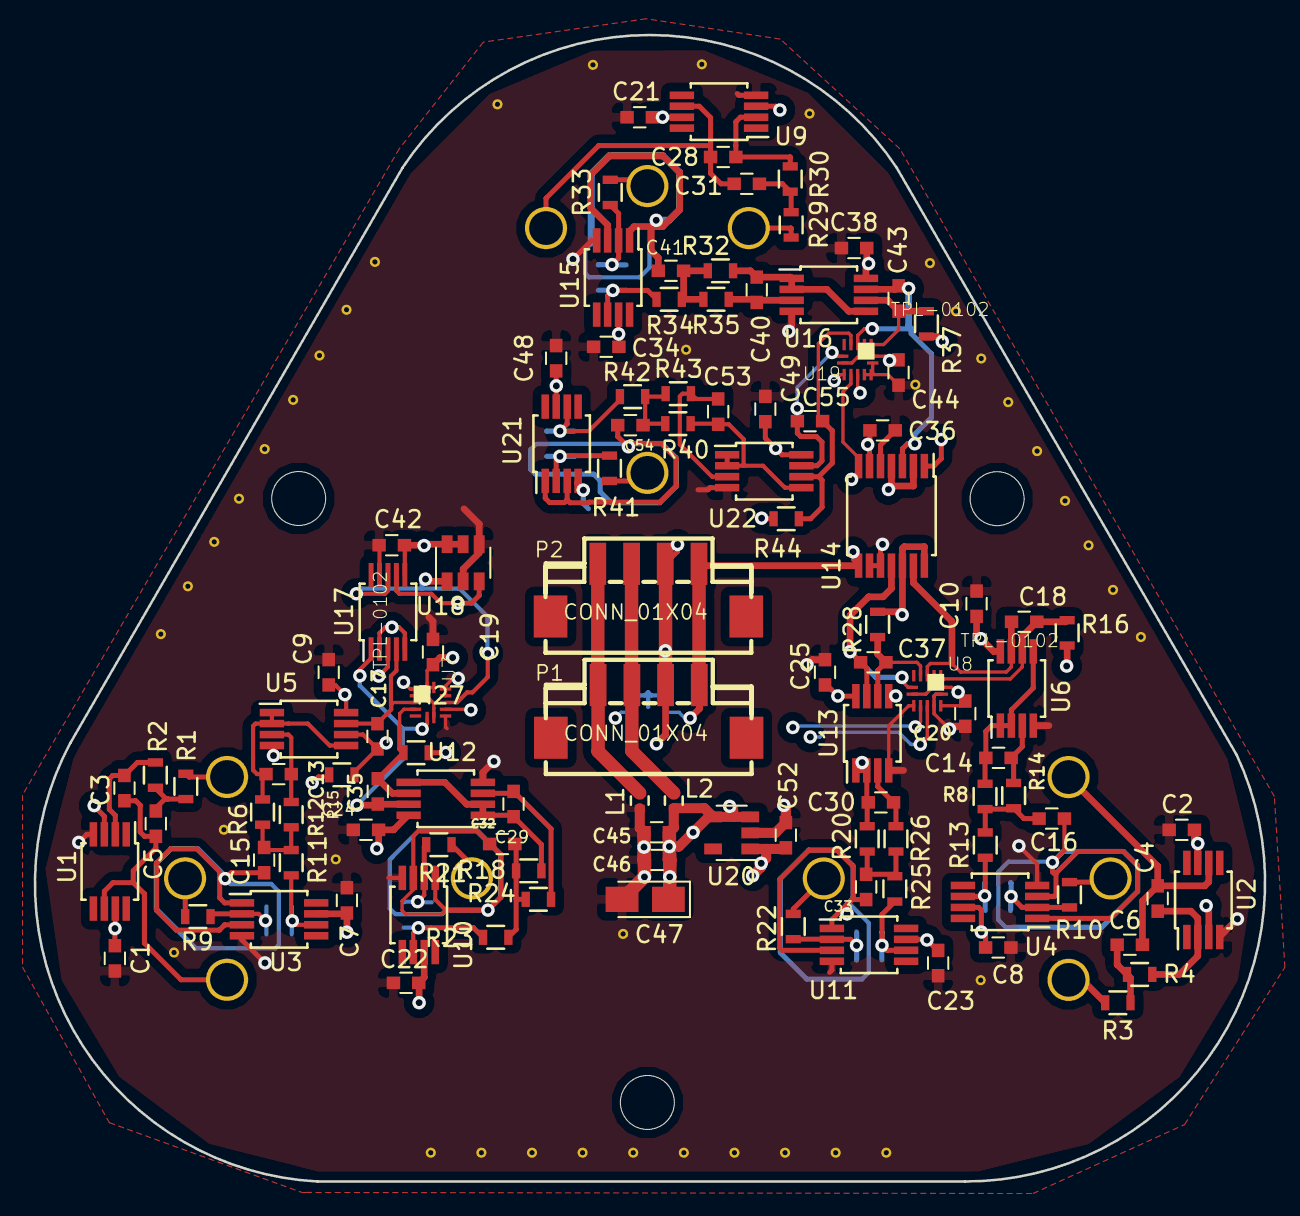
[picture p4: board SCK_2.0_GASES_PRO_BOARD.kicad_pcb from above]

Board: 4 copper layers, 72.9 x 68.0 mm, 126 parts (0 on the bottom side), 67 nets.

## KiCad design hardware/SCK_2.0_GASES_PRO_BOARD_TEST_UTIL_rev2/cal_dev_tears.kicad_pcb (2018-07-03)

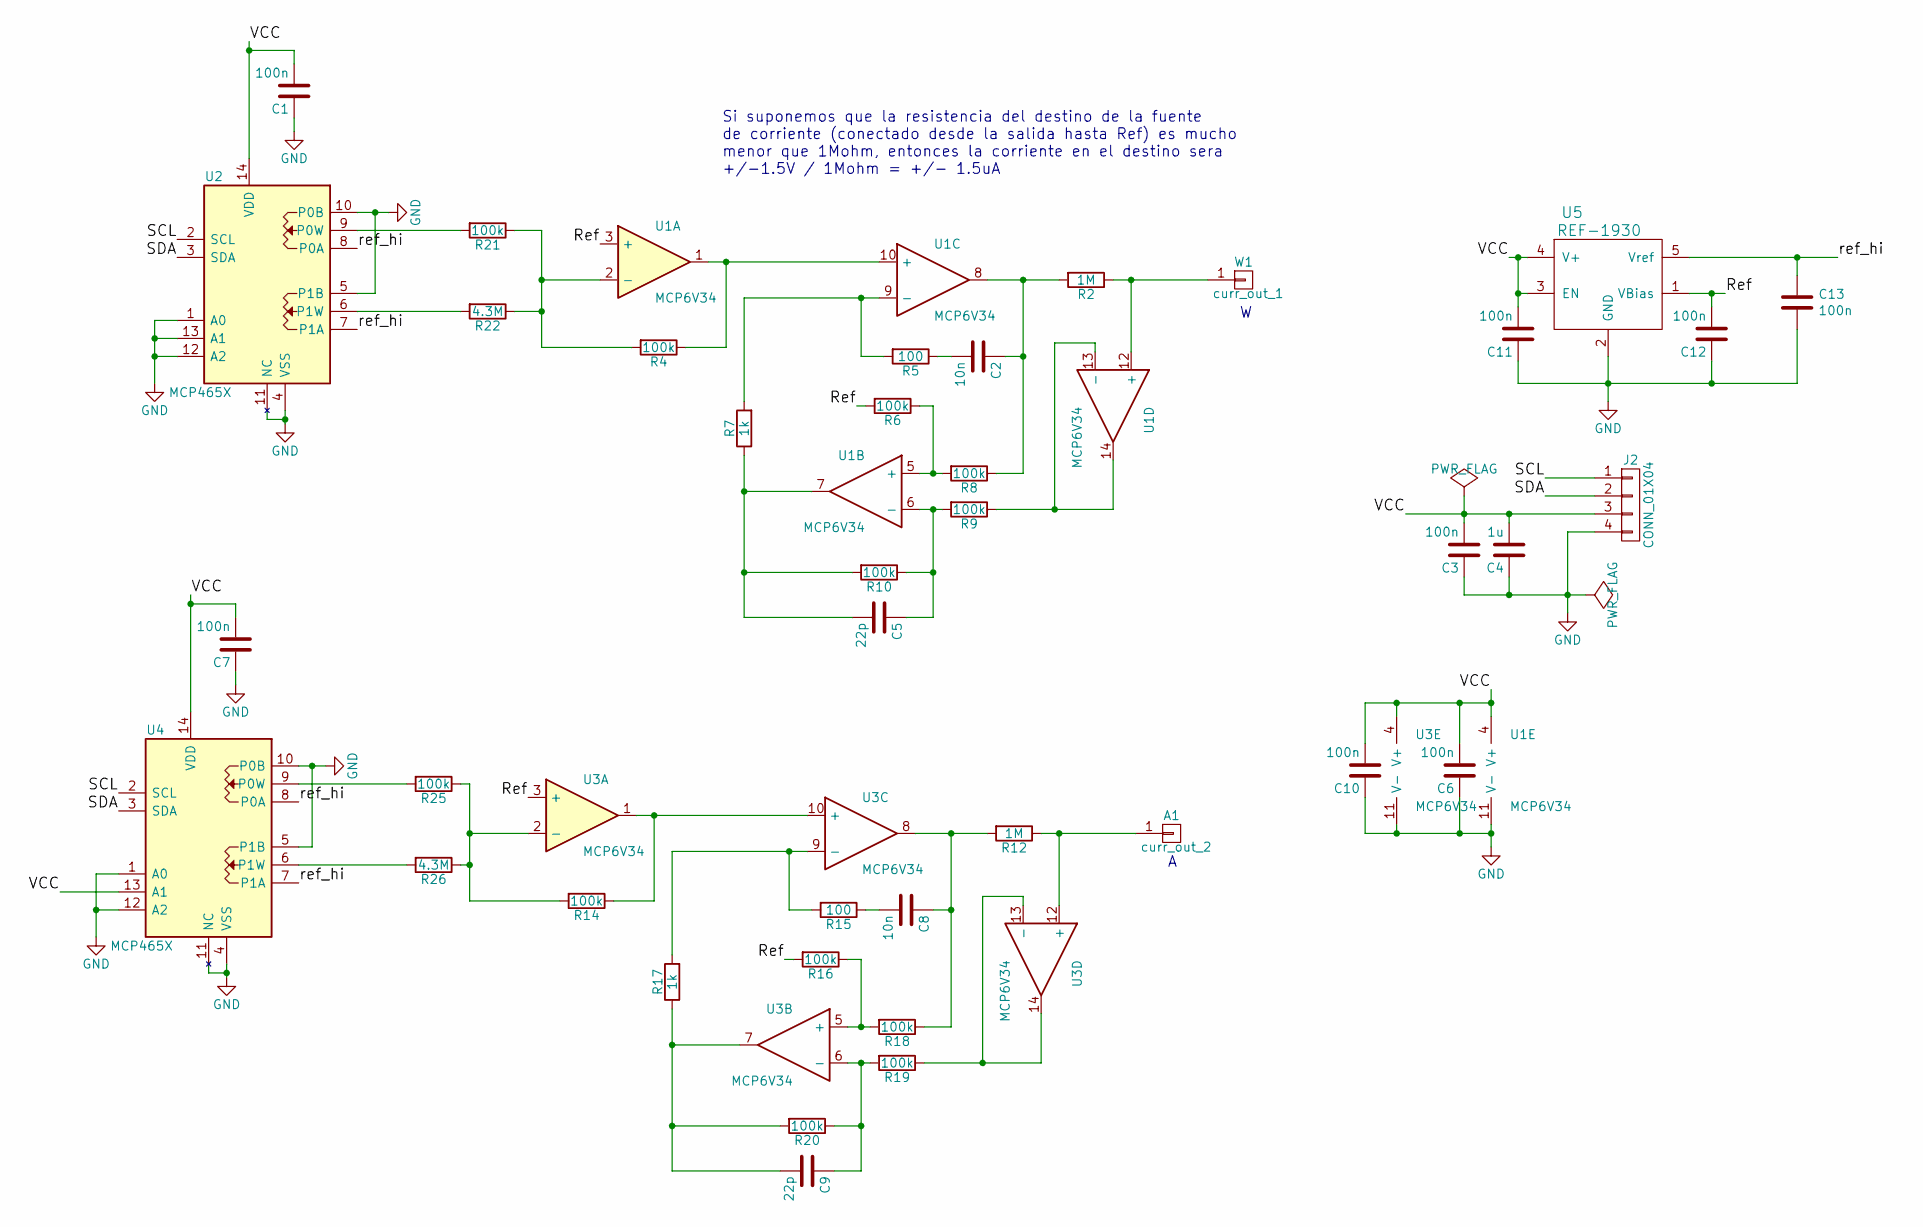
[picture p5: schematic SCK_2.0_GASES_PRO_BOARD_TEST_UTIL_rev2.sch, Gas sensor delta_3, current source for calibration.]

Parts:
A1: curr_out_2; 1pin
C1, C3, C6, C7, C10, C11, C12, C13: 100n; C_0603_HandSoldering
C2, C8: 10n; C_0603_HandSoldering
C4: 1u; C_0603_HandSoldering
C5, C9: 22p; C_0603_HandSoldering
J2: CONN_01X04; HW4-SMD-2.0
R2, R12: 1M; R_0805_HandSoldering
R4, R6, R8, R9, R10, R14, R16, R18, R19, R20, R21, R25: 100k; R_0603_HandSoldering
R5, R15: 100; R_0603_HandSoldering
R7, R17: 1k; R_0603_HandSoldering
R22, R26: 4.3M; R_0603_HandSoldering
U1, U3: MCP6V34; TSSOP-14_4.4x5mm_Pitch0.65mm
U2, U4: MCP465X; TSSOP-14_4.4x5mm_Pitch0.65mm
U5: REF-1930; SOT-23-5
W1: curr_out_1; 1pin

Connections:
/Ref: C12.2, R6.2, R16.2, U1.3 (+), U3.3 (+), U5.1 (VBias)
/SCL: J2.1, U2.2 (SCL), U4.2 (SCL); also elsewhere on the board
/SDA: J2.2, U2.3 (SDA), U4.3 (SDA); also elsewhere on the board
/VCC: C1.2, C3.2, C4.2, C6.2, C7.2, C10.2, C11.2, J2.3, U1.4 (V+), U2.14 (VDD), U3.4 (V+), U4.13 (A1), U4.14 (VDD), U5.3 (EN), U5.4 (V+); also elsewhere on the board
/ref_hi: C13.2, U2.7 (P1A), U2.8 (P0A), U4.7 (P1A), U4.8 (P0A), U5.5 (Vref)
GND: C1.1, C3.1, C4.1, C6.1, C7.1, C10.1, C11.1, C12.1, C13.1, J2.4, U1.11 (V-), U2.1 (A0), U2.4 (VSS), U2.5 (P1B), U2.10 (P0B), U2.11 (NC), U2.12 (A2), U2.13 (A1), U3.11 (V-), U4.1 (A0), U4.4 (VSS), U4.5 (P1B), U4.10 (P0B), U4.11 (NC), U4.12 (A2), U5.2 (GND); also elsewhere on the board
unnamed: C2.1, R2.2, R8.1, U1.8
unnamed: C2.2, R5.1
unnamed: C5.1, R9.2, R10.1, U1.6 (-)
unnamed: C5.2, R7.1, R10.2, U1.7
unnamed: C8.1, R12.2, R18.1, U3.8
unnamed: C8.2, R15.1
unnamed: C9.1, R19.2, R20.1, U3.6 (-)
unnamed: C9.2, R17.1, R20.2, U3.7
unnamed 14: R2.1, U1.12 (+), W1.1; also elsewhere on the board
unnamed 15: A1.1, R12.1, U3.12 (+); also elsewhere on the board
unnamed: R4.1, U1.1, U1.10 (+)
unnamed: R5.2, R7.2, U1.9 (-)
unnamed: R6.1, R8.2, U1.5 (+)
unnamed: R9.1, U1.13 (-), U1.14
unnamed: R14.1, U3.1, U3.10 (+)
unnamed: R14.2, R25.1, R26.1, U3.2 (-)
unnamed: R15.2, R17.2, U3.9 (-)
unnamed: R16.1, R18.2, U3.5 (+)
unnamed: R19.1, U3.13 (-), U3.14
unnamed: R4.2, R21.1, R22.1, U1.2 (-)
unnamed: R21.2, U2.9 (P0W)
unnamed: R22.2, U2.6 (P1W)
unnamed: R25.2, U4.9 (P0W)
unnamed: R26.2, U4.6 (P1W)

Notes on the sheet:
Si suponemos que la resistencia del destino de la fuente de corriente (conectado desde la salida hasta Ref) es mucho menor que 1Mohm, entonces la corriente en el destino sera +/-1.5V / 1Mohm = +/- 1.5uA

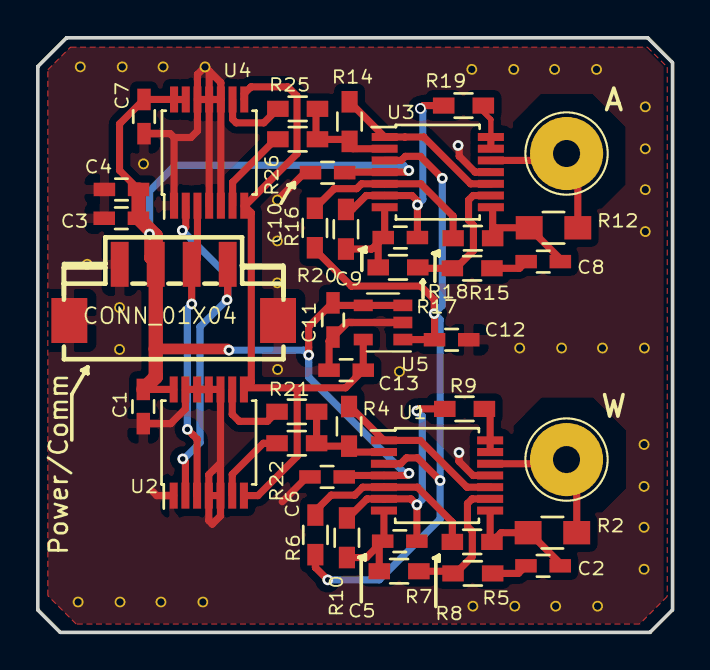
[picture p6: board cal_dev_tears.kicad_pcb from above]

Board: 2 copper layers, 35.3 x 33.0 mm, 41 parts (0 on the bottom side), 30 nets.

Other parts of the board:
A: curr_out_2; 1pin
Power/Comm: CONN_01X04; HW4-SMD-2.0
W: curr_out_1; 1pin

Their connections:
/SCL: Power/Comm.1; also elsewhere on the board
/SDA: Power/Comm.2; also elsewhere on the board
/VCC: Power/Comm.3; also elsewhere on the board
GND: Power/Comm.4, Power/Comm.SS1, Power/Comm.SS2; also elsewhere on the board
unnamed 14: W.1; also elsewhere on the board
unnamed 15: A.1; also elsewhere on the board

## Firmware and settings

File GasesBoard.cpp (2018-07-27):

#include <GasesBoard.h>

bool GasesBoard::start()
{
	if (alreadyStarted) return true;

	if (!I2Cdetect(sht31Address) ||
			!(I2Cdetect(Slot1.electrode_A.resistor.address)) ||
			!(I2Cdetect(Slot1.electrode_W.resistor.address)) ||
			!(I2Cdetect(Slot2.electrode_A.resistor.address)) ||
			!(I2Cdetect(Slot2.electrode_W.resistor.address)) ||
			!(I2Cdetect(Slot3.electrode_A.resistor.address)) ||
			!(I2Cdetect(Slot3.electrode_W.resistor.address))) return false;

	sht31.start();

	// Set all potentiometers to 0
	setPot(Slot1.electrode_A, 0);
	setPot(Slot1.electrode_W, 0);
	setPot(Slot2.electrode_A, 0);
	setPot(Slot2.electrode_W, 0);
	setPot(Slot3.electrode_A, 0);
	setPot(Slot3.electrode_W, 0);

	alreadyStarted = true;

	return true;
}

bool GasesBoard::stop()
{
	sht31.stop();
	// TODO minimize power consumption
	return true;
}

float GasesBoard::getTemperature()
{
	sht31.update(true);
	return sht31.temperature;
}
float GasesBoard::getHumidity()
{
	sht31.update(true);
	return sht31.humidity;
}
uint32_t GasesBoard::getPot(Electrode wichElectrode)
{

	return ((255 - readI2C(wichElectrode.resistor.address, wichElectrode.resistor.channel)) * ohmsPerStep);
}
void GasesBoard::setPot(Electrode wichElectrode, uint32_t value)
{

	int data=0x00;
	if (value>100000) value = 100000;
	data = 255 - (int)(value/ohmsPerStep);		// POT's are connected 'upside down' (255 - step)

	writeI2C(wichElectrode.resistor.address, 16, 192);        	// select WR (volatile) registers in POT
	writeI2C(wichElectrode.resistor.address, wichElectrode.resistor.channel, data);
}
uint8_t GasesBoard::getPGAgain(MCP342X adc)
{
	uint8_t gainPGA = adc.getConfigRegShdw() & 0x3;
	return pow(2, gainPGA);
}
float GasesBoard::getElectrodeGain(Electrode wichElectrode)
{

	return (((getPot(wichElectrode) + 85) / 10000.0f) + 1) * getPGAgain(wichElectrode.adc);
}
// Returns electrode value in mV
double GasesBoard::getElectrode(Electrode wichElectrode)
{

	static int32_t result;

	// Gain can be changed before calling this funtion with: wichElectrode.gain = newGain (0->gain of 1, 1->gain of 2, 2->gain of 3 or 3->gain of 8)
	wichElectrode.adc.configure( MCP342X_MODE_ONESHOT | MCP342X_SIZE_18BIT | wichElectrode.gain);
	wichElectrode.adc.startConversion(wichElectrode.channel);
	wichElectrode.adc.getResult(&result);

	return (result * 0.015625) / getElectrodeGain(wichElectrode);
}
float GasesBoard::getPPM(gasesBoardSensor wichSlot)
{
    switch(wichSlot.calData.GAS) {

        case GB_CO: {
            // CO [ppm] = ((6.36 * WE - ZERO_CURR_W) - n*(6.36 * AE + ZERO_CURR_A)) / SENSITIVITY
            float resultCO = ((6.36 * getElectrode(wichSlot.electrode_W)) - wichSlot.calData.ZERO_CURR_W -
                  wichSlot.calData.ZERO_CURR_W/wichSlot.calData.ZERO_CURR_A * (6.36 * getElectrode(wichSlot.electrode_A) - wichSlot.calData.ZERO_CURR_A)) /
                  wichSlot.calData.SENSITIVITY[0];
	    resultCO =  max(0, resultCO);
	    return resultCO;
            break;

	} case GB_NO2: {
            // NO2 [ppm] = ((6.36 * WE - ZERO_CURR_W) - n*(6.36 * AE - ZERO_CURR_A)) / SENSITIVITY
            // NO2 [ppb] = ((6.36 * WE - ZERO_CURR_W) - n*(6.36 * AE - ZERO_CURR_A)) / SENSITIVITY
            float resultNO2 = (((6.36 * getElectrode(wichSlot.electrode_W) - wichSlot.calData.ZERO_CURR_W) -
                wichSlot.calData.ZERO_CURR_W/wichSlot.calData.ZERO_CURR_A * (6.36 * getElectrode(wichSlot.electrode_A)-wichSlot.calData.ZERO_CURR_A)) /
                wichSlot.calData.SENSITIVITY[0]) * 1000;
	    resultNO2 =  max(0, resultNO2);
	    return resultNO2;
            break;

	} case GB_NO2_O3: {
	    // O3 [ppm] =  ((6.36 * WE - ZERO_CURR_W) - n*(6.36 * AE - ZERO_CURR_A) - getPPM(NO2) * SENSITIVITY_NO2) / SENSITIVITY_O3
	    float resultO3 = ((6.36 * getElectrode(wichSlot.electrode_W) - wichSlot.calData.ZERO_CURR_W) -
		  ((wichSlot.calData.ZERO_CURR_W / wichSlot.calData.ZERO_CURR_A) * (6.36 * getElectrode(wichSlot.electrode_A) - wichSlot.calData.ZERO_CURR_A)) -
		  ((getPPM(Slot2) / 1000) * wichSlot.calData.SENSITIVITY[1])) /
		    wichSlot.calData.SENSITIVITY[0];
	    resultO3 =  max(0, resultO3);
	    return resultO3;
            break;
	}
    }
    return 0;
}
String GasesBoard::getUID()
{

	char data[24];
	uint8_t eeaddr = 0xf8;
	sprintf(data, "%02x:", readByte(eeaddr++));
	for(uint8_t pos = 0; pos<7; pos++){
		sprintf(data, "%s:%02x", data, readByte(eeaddr++));
	}
	return String(data);
}
bool GasesBoard::writeByte(uint8_t dataAddress, uint8_t data)
{
	WIRE.beginTransmission(eepromAddress);
	WIRE.write(dataAddress);
	WIRE.write(data);
	if (WIRE.endTransmission() == 0) return true;
	return false;
}
uint8_t GasesBoard::readByte(uint8_t dataAddress)
{
	WIRE.beginTransmission(eepromAddress);
	WIRE.write(dataAddress);
	if (WIRE.endTransmission(false)) return 0;
	if(!WIRE.requestFrom(eepromAddress, 1)) return 0;
	return WIRE.read();
}
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

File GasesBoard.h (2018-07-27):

#pragma once

#include <MCP342X.h>

#define SCKVER 20 // If the library is going to be used in SCK 2.0 uncoment this line
/* #define SCKVER 15 // If the library is going to be used in SCK 1.5 uncoment this line */

// Gases Board Tester (Only supported in version 2.0 and greater)
/* #define gasesBoardTest 	// Uncomment for enabling tester board support (remember selecting board lookup table in GasesBoardTester.h) */

#if SCKVER>15
extern TwoWire auxWire;
#define WIRE auxWire
#ifdef gasesBoardTest
#include "GasesBoardTester.h"
#endif

#else
#define WIRE Wire
#endif

// Temperature and Humidity
class Gases_SHT31
{
	// Datasheet
	// https://www.sensirion.com/fileadmin/user_upload/customers/sensirion/Dokumente/2_Humidity_Sensors/Sensirion_Humidity_Sensors_SHT3x_Datasheet_digital.pdf
	// This code is based on Adafruit SHT31 library, thanks! (https://github.com/adafruit/Adafruit_SHT31)
	private:

		TwoWire *_Wire;

		// Commands
		const uint16_t SOFT_RESET = 0x30A2;
		const uint16_t SINGLE_SHOT_HIGH_REP = 0x2400;

		uint32_t timeout = 15;	// Time in ms to wait for a reading
		uint32_t lastTime = 0;
		void sendComm(uint16_t comm);
		uint8_t crc8(const uint8_t *data, int len);
	public:
		uint8_t address = 0x44;
		// Conntructor
		Gases_SHT31(TwoWire *localWire); 

		float temperature;
		float humidity;
		bool start();
		bool stop();
		bool update(bool wait=true);
};

struct Resistor
{
	byte address;
	byte channel;
};

struct Electrode
{
	MCP342X adc;
	byte channel;
	Resistor resistor;
	uint8_t gain;
};

enum GB_GAS
{
	GB_CO,
	GB_NO2,
	GB_NO2_O3
};

struct CalibrationData
{
	GB_GAS GAS;
	float ZERO_CURR_W;
	float ZERO_CURR_A;
	float SENSITIVITY[2];
};

struct gasesBoardSensor
{
	Electrode electrode_A;
	Electrode electrode_W;
	CalibrationData calData;
};

class GasesBoard
{
	public:

		// Init functions
		bool start();
		bool stop();
		bool alreadyStarted = false;

		// SHT31 Temperature and Humidity Sensor
		const byte sht31Address = 0x44;

		// Adafruit_SHT31 sht31 = Adafruit_SHT31();
		Gases_SHT31 sht31 = Gases_SHT31(&WIRE);

		float getTemperature();
		float getHumidity();


		// Alphasense Sensors (Slot 1,2 and 3)
		const uint8_t initGain = 0; 	// (0->gain of 1, 1->gain of 2, 2->gain of 3 or 3->gain of 8)
		const float ohmsPerStep = 392.1568;     // Resistor conversion constant in Ohms. (100,000 / 255)
		MCP342X ADC_1 = MCP342X(0x69, &WIRE);
		MCP342X ADC_2_3 = MCP342X(0x68, &WIRE);

		// Slot 1 sensor
		gasesBoardSensor Slot1 = {
			{ADC_1, MCP342X_CHANNEL_1, {0x55, 0x01}, initGain},		// Electrode A
			{ADC_1, MCP342X_CHANNEL_2, {0x55, 0x00}, initGain},		// Electrode W
			{GB_CO, (-68.1), (-13.9), {601.9, 0}} // board U		// Gas type, zero current W, zero current A, sensitivity TODO move this to eeprom inside alpha board
			/* {GB_CO, (-69.4), (-18.6), {493.1, 0}} // board 1 */
		};

		// Slot 2 sensor
		gasesBoardSensor Slot2 = {
			{ADC_2_3, MCP342X_CHANNEL_3, {0x56, 0x01}, initGain},		// Electrode A
			{ADC_2_3, MCP342X_CHANNEL_4, {0x56, 0x00}, initGain},		// Electrode W
			{GB_NO2, 31.5, 17.7, {(-383.7), 0}} // Board U
			/* {GB_NO2, 25.9, 15.4, {(-384.9), 0}} // Board 1 */
		};

		// Slot 3 sensor
		gasesBoardSensor Slot3 = {
			{ADC_2_3, MCP342X_CHANNEL_1, {0x54, 0x01}, initGain},		// Electrode A
			{ADC_2_3, MCP342X_CHANNEL_2, {0x54, 0x00}, initGain},		// Electrode W
			{GB_NO2_O3, 23.01, 14.5, {(-446.36), (-506.96)}} // Board U
			/* {GB_NO2_O3, 23.33, 19.86, {(-466.29), (-466.29)}} // Board 1 */

		};

		uint32_t getPot(Electrode wichElectrode);				// Return value in Ohms
		void setPot(Electrode wichElectrode, uint32_t value);	// Accept value in Ohms (0-100,000)
		uint8_t getPGAgain(MCP342X adc);
		float getElectrodeGain(Electrode wichElectrode);
		double getElectrode(Electrode wichElectrode);
		float getPPM(gasesBoardSensor wichSlot);
		String getUID();
		bool writeByte(uint8_t dataAddress, uint8_t data);
		uint8_t readByte(uint8_t dataAddress);

		#ifdef gasesBoardTest
		testerGasesBoard tester;
		double preVoltA = -99;
		double preVoltW = -99;
		double threshold = 0.05;
		uint8_t maxErrorsA = 5;
		uint8_t maxErrorsW = 5;
		void runTester(uint8_t wichSlot);
		void setTesterCurrent(int16_t wichCurrent, uint8_t wichSlot);
		bool autoTest();
		#endif

	private:

		// EEPROM 24AA025
		const byte eepromAddress = 0x51;

		bool I2Cdetect(byte address);
		void writeI2C(byte deviceaddress, byte instruction, byte data );
		byte readI2C(byte deviceaddress, byte instruction);

};

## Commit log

2018-07-03 First release
    [SCK_2.0_GASES_PRO_BOARD.dsn, SCK_2.0_GASES_PRO_BOARD.kicad_pcb, SCK_2.0_GASES_PRO_BOARD.sch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]
2018-07-20 Gases board as a separate library
2018-07-20 No tester support as default to avoid overhead
    [GasesBoard.h]
2018-07-20 Fix on ADC declaration not passing right Wire interface
    [GasesBoard.h]
2018-07-23 Support for SCK 2.0 separated I2C interface
2019-02-14 Updates BOM
    [SCK_2.0_GASES_PRO_BOARD_BOM.csv, SCK_2.0_GASES_PRO_BOARD_BOM.ods, SCK_2.0_GASES_PRO_BOARD_TEST_UTIL_rev2_BOM.csv]
